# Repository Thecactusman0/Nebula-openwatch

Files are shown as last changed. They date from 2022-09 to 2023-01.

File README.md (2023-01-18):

# Nebula-openwatch
Nebula is a ESP32 based smartwatch proof of concept that features a rotating bezel encoder along with a suite of sensors and parts. This includes:

-ESP32-S3-MINI with wifi and bluetooth LE capabilities

-3 pushbuttons, 2 programmable

-I2C Ambient light sensor for automatic screen dimming

-Onboard lipo charging

-Onboard ldo regulator with voltage supervisor

-I2S amplifier for audio output (BLUETOOTH LE DOES NOT SUPPORT STREAMING AUDIO,CHANGES ARE NEEDED TO BOARD TO ENABLE USE OF THIS CHIP)

-I2S Mems microphone for  audio input(BLUETOOTH LE DOES NOT SUPPORT STREAMING AUDIO)

-I2C RTC module (HASNT BEEN SUFFICENTLY TESTED)

-Haptic vibration motor for user feedback

-4 pin dock connector (2.54 female header) for use with dock that provides serial programming and power.

-I2C 3 axis gyroscope and accelerometer

-200mah lipo battery

Total size is ~44mm diameter, ~12mm height

DO NOT BUILD PROOF OF CONCEPT FOR REFERENCE ONLY

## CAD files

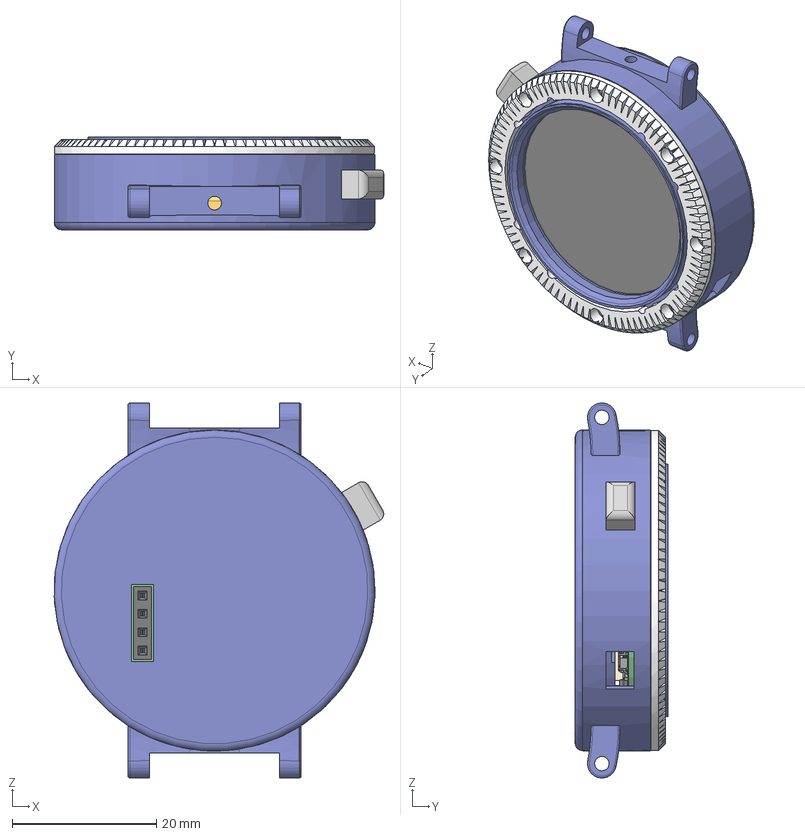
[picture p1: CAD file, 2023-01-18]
Nebula - Master/3D print models/Nebula V2 Bearing type v4.step
45.7 x 12.8 x 52.0 mm
Nebula PCB
Glass
Display
Brass fitting x 4
Resistor - 0603 x 3
Capacitor - 0603 x 5
JST - PH - SMD (R) - 8Pin - 2.00mm
SOT23-3
SOT23-5
Esp module
Battery 200
Case
Bottom
Ring
Button

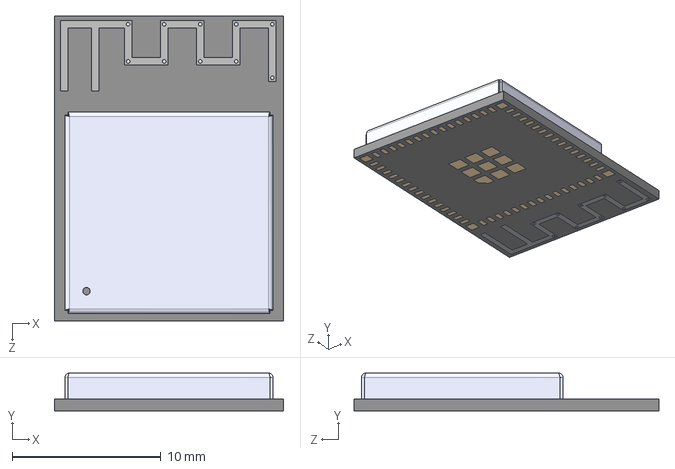
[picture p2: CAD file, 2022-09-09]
Nebula - Master/Footprint/ESP32-S3-MINI-1-N8.step
15.4 x 2.55 x 20.5 mm

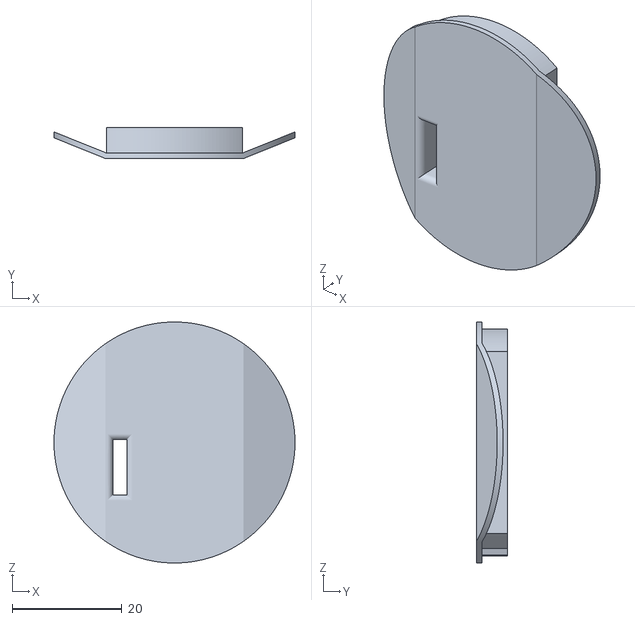
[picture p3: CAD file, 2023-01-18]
Nebula - Master/Kicad/Watch/bottom2.stl
44.0 x 5.65 x 44.0

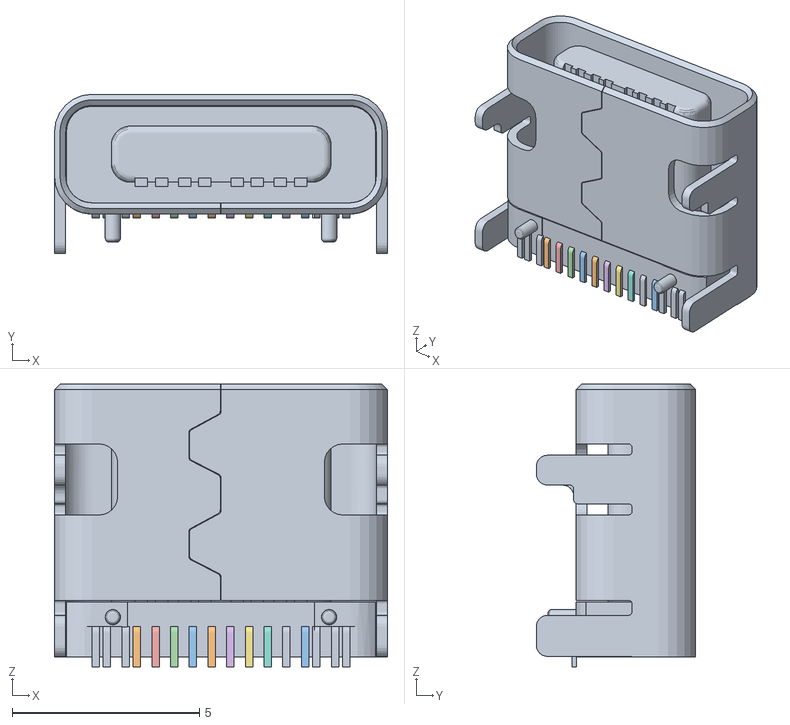
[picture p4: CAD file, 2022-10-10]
Nebula - Master/Models/u262-16xn-4bvc11.obj
8.90 x 4.26 x 7.56
u262-16xn-4bvc11_1
u262-16xn-4bvc11_2
u262-16xn-4bvc11_3
u262-16xn-4bvc11_4
u262-16xn-4bvc11_5
u262-16xn-4bvc11_6
u262-16xn-4bvc11_7
u262-16xn-4bvc11_8
u262-16xn-4bvc11_9
u262-16xn-4bvc11_10
u262-16xn-4bvc11_11

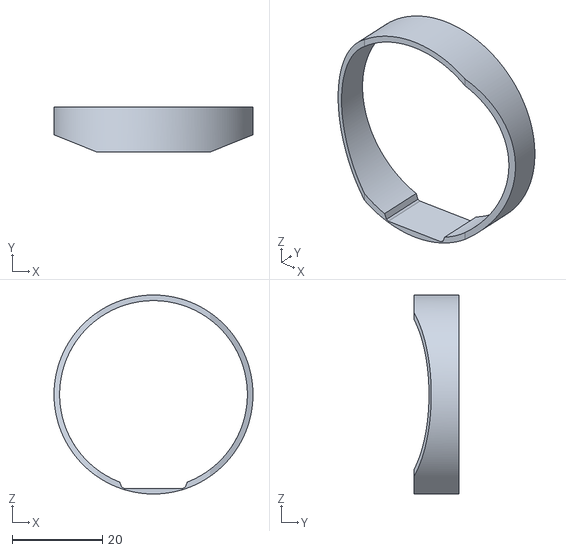
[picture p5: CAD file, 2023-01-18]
Nebula - Master/Kicad/Watch/case2.stl
44.0 x 10.0 x 44.0

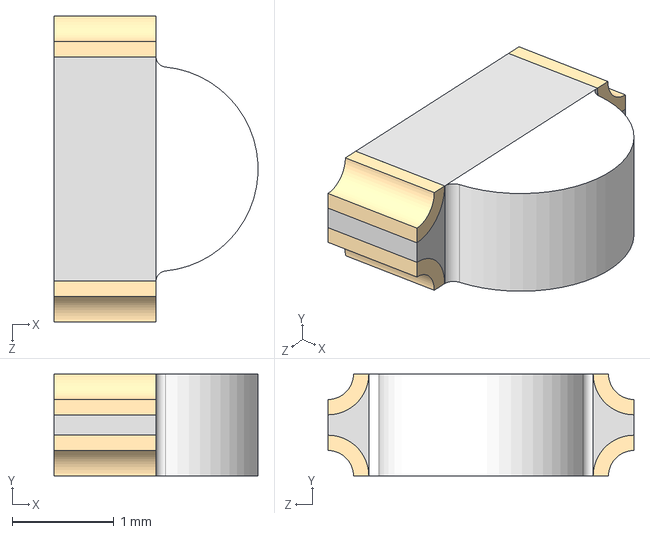
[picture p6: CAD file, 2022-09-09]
Nebula - Master/Models/LTST-S326KGJRKT.step
2.00 x 1.00 x 3.00 mm

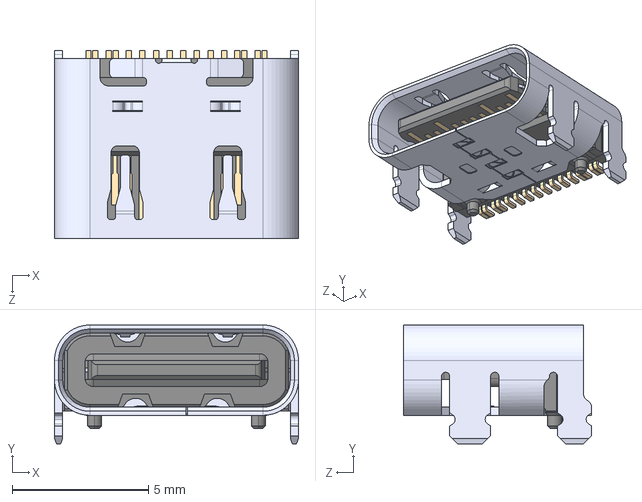
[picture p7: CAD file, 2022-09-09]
Nebula - Master/Models/DX07S016JA1R1500.step
8.94 x 4.36 x 6.90 mm

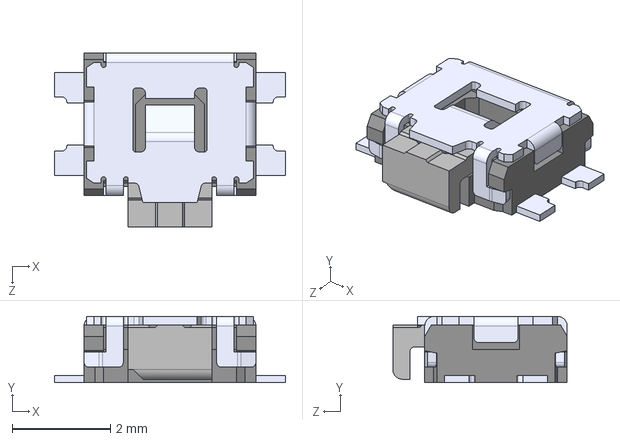
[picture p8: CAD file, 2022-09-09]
Nebula - Master/Models/EVQ-P7J01P.step
4.70 x 1.35 x 3.55 mm

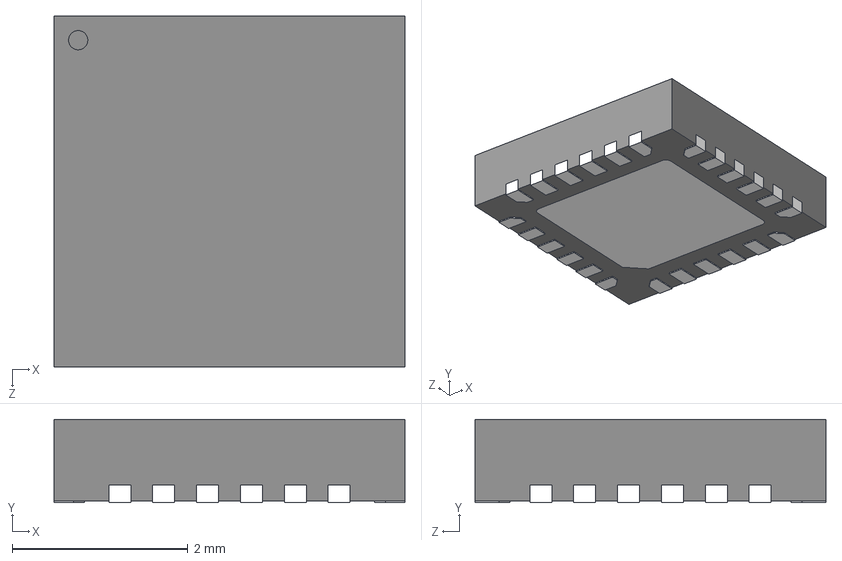
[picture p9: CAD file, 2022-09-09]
Nebula - Master/Models/MPU6050.step
4.00 x 0.95 x 4.00 mm

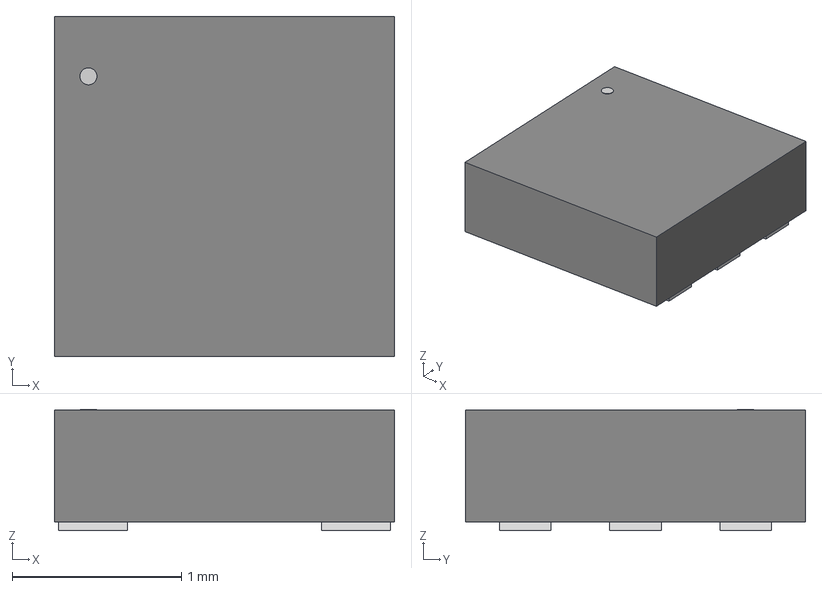
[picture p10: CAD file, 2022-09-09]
Nebula - Master/Models/LTR-303ALS-01_LTO.step
2.01 x 2.01 x 0.714 mm

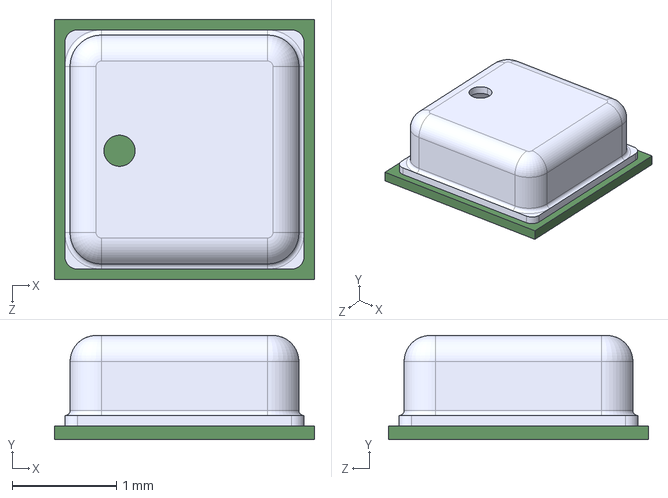
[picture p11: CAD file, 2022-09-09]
Nebula - Master/Models/BME280.step
2.50 x 1.00 x 2.50 mm

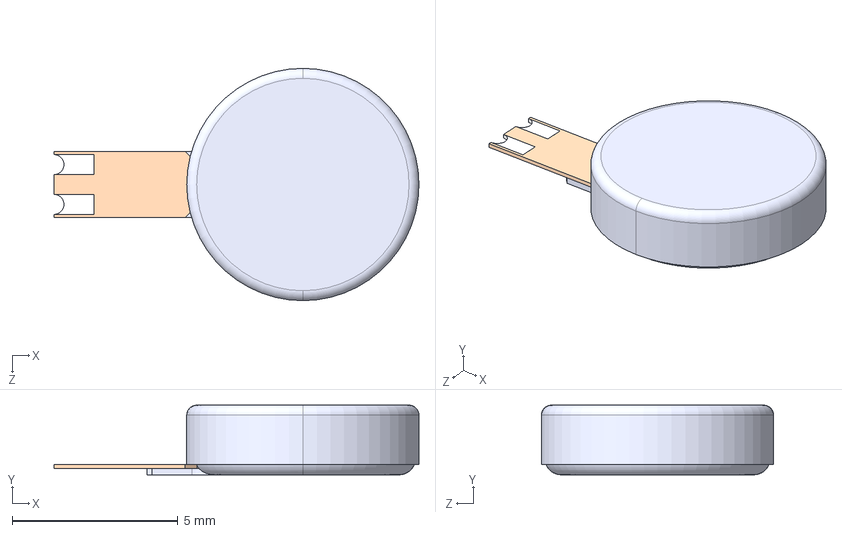
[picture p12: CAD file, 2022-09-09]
Nebula - Master/Models/C0720B001F.step
11.0 x 2.10 x 7.00 mm

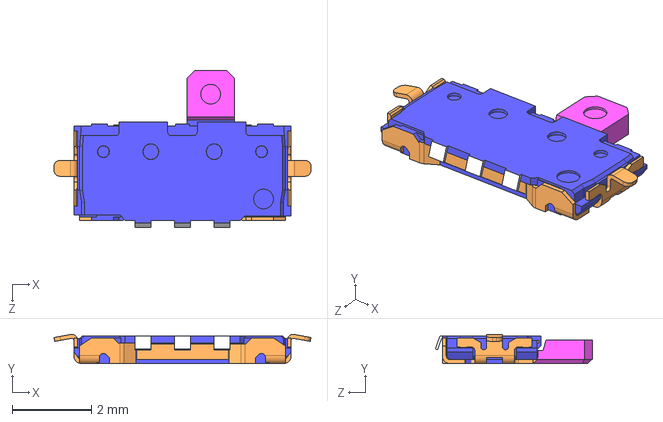
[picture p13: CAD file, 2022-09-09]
Nebula - Master/Models/SSAJ120100.STEP
6.50 x 0.74 x 3.98 mm

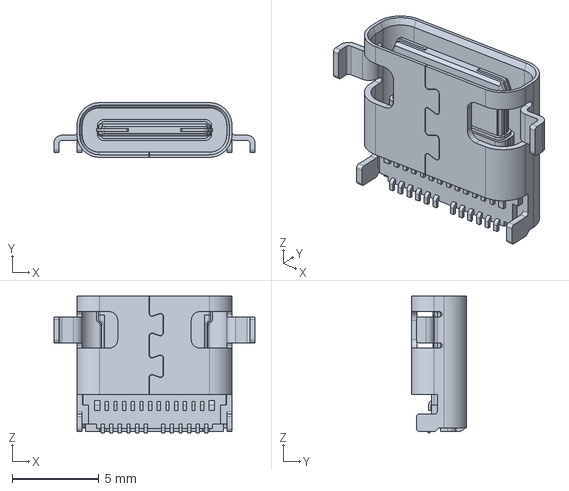
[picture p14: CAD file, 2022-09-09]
Nebula - Master/Models/1054550101.step
11.6 x 3.16 x 7.90 mm

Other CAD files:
Nebula - Master/Models/MCP73831T-2ATI_OT.step

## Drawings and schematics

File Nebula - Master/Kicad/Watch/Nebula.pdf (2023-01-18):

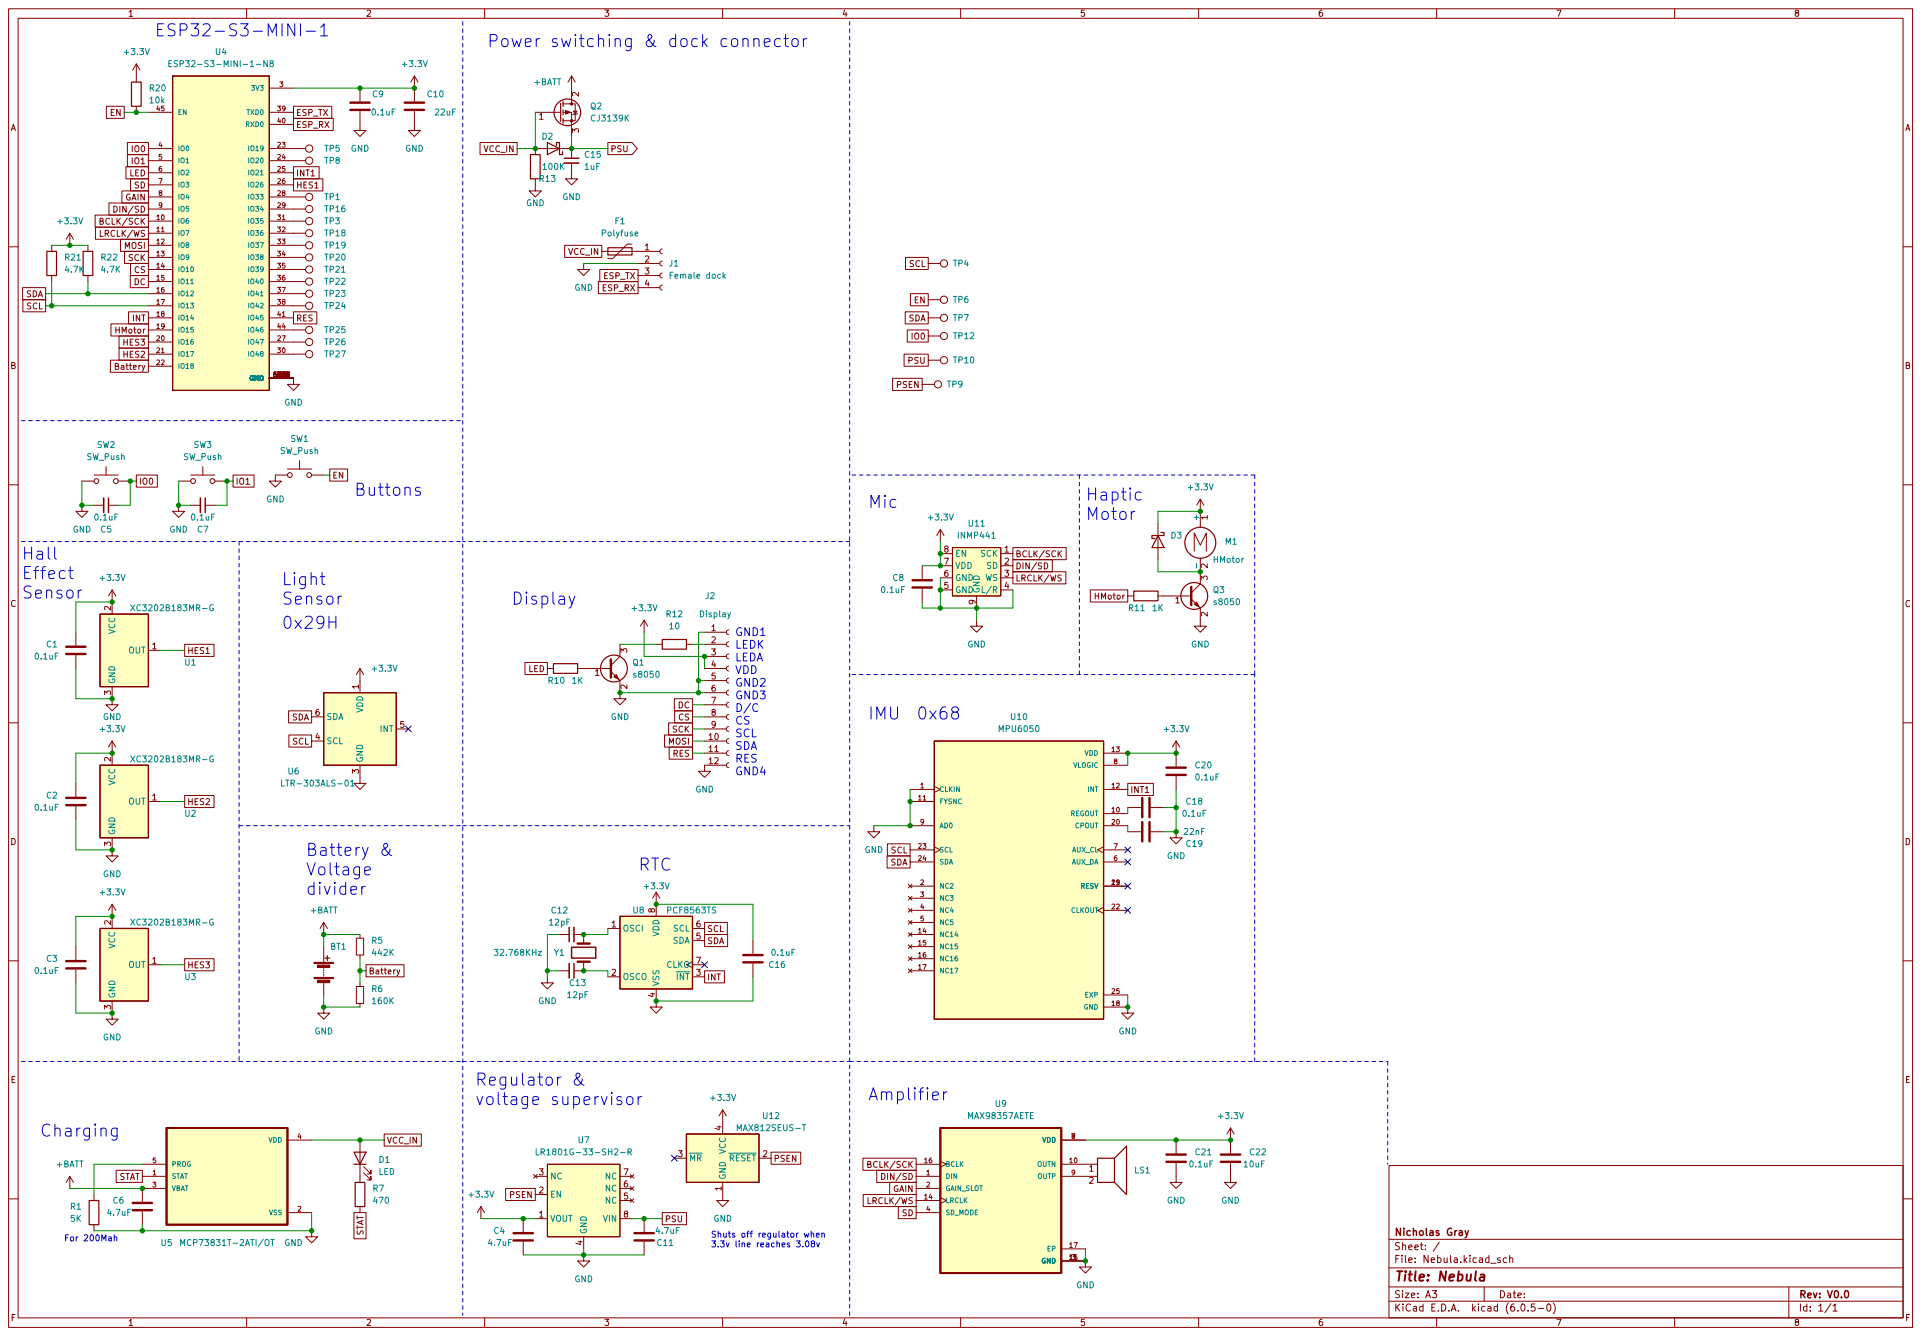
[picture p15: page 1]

Power switching & dock connector

Shuts off regulator when
3.3v line reaches 3.08v

File: Nebula.kicad_sch Sheet: / Nicholas Gray

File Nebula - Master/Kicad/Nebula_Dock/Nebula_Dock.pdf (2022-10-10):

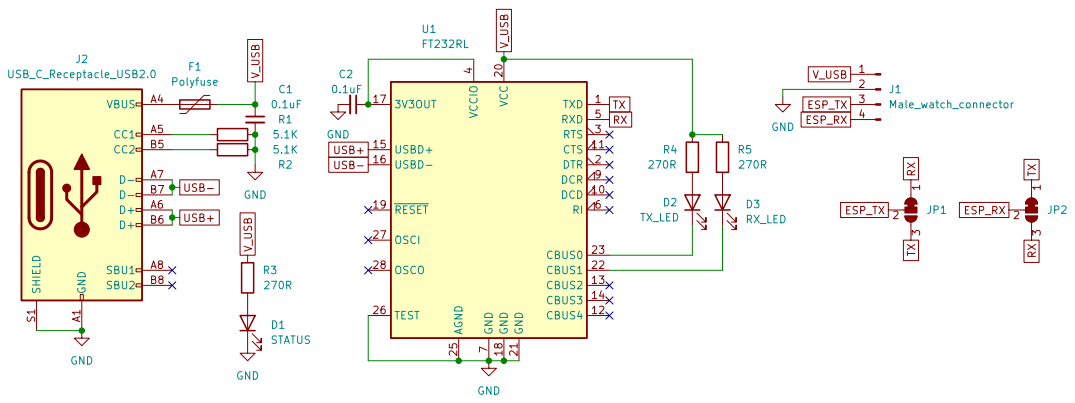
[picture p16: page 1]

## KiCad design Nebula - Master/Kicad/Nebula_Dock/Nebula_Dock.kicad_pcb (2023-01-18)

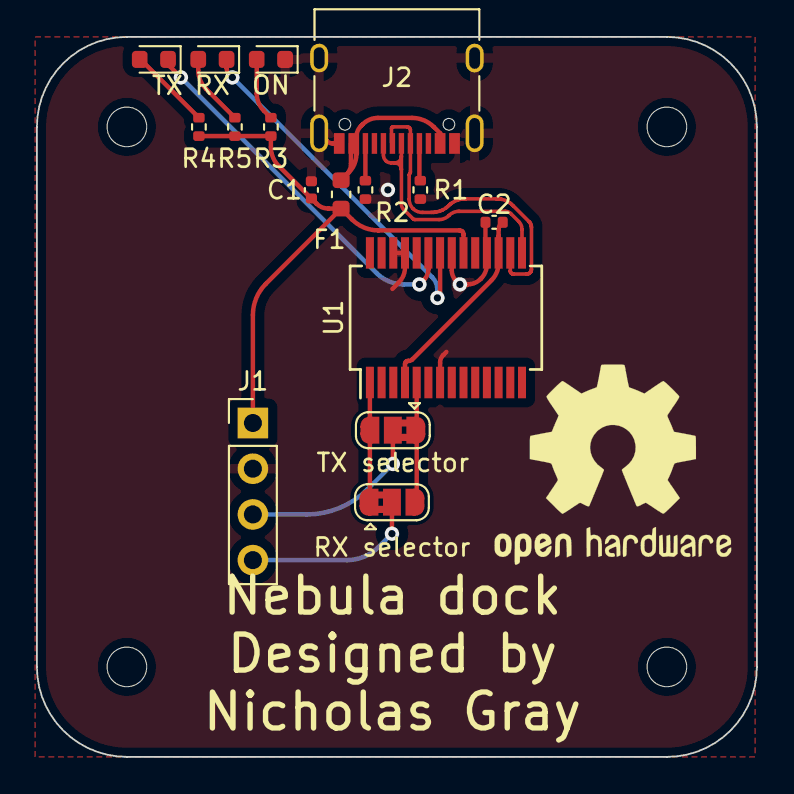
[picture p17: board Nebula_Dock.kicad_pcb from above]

Board: 2 copper layers, 40.0 x 40.0 mm, 20 parts (0 on the bottom side), 17 nets.

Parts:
C1, C2: 0.1uF; C_0402_1005Metric
F1: Polyfuse; Fuse_0603_1608Metric
J1: Male_watch_connector; PinHeader_1x04_P2.54mm_Vertical
J2: USB_C_Receptacle_USB2.0; USB_C_Receptacle_XKB_U262-16XN-4BVC11
ON: STATUS; LED_0603_1608Metric
R1, R2: 5.1K; R_0402_1005Metric
R3, R4, R5: 270R; R_0402_1005Metric
REF1, REF2, REF3, REF4: MountingHole_2.2mm_M2
RX: RX_LED; LED_0603_1608Metric
RX selector: SolderJumper_3_Bridged12; SolderJumper-3_P1.3mm_Bridged2Bar12_RoundedPad1.0x1.5mm
TX: TX_LED; LED_0603_1608Metric
TX selector: SolderJumper_3_Bridged12; SolderJumper-3_P1.3mm_Bridged2Bar12_RoundedPad1.0x1.5mm
U1: FT232RL; SSOP-28_5.3x10.2mm_P0.65mm

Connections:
ESP_RX: J1.4, RX selector.2 (C)
ESP_TX: J1.3, TX selector.2 (C)
GND: C1.2, C2.2, J1.2, J2.A1 (GND), J2.A12 (GND), J2.B1 (GND), J2.B12 (GND), J2.S1 (SHIELD), ON.1 (K), R1.2, R2.1, U1.7 (GND), U1.18 (GND), U1.21 (GND), U1.25 (AGND), U1.26 (TEST)
unnamed: C2.1, U1.4 (VCCIO), U1.17 (3V3OUT)
unnamed: ON.2 (A), R3.2
unnamed: TX.1 (K), U1.23 (CBUS0)
unnamed: R4.2, TX.2 (A)
unnamed: RX.1 (K), U1.22 (CBUS1)
unnamed: R5.2, RX.2 (A)
unnamed: F1.1, J2.A4 (VBUS), J2.A9 (VBUS), J2.B4 (VBUS), J2.B9 (VBUS)
unnamed: J2.A5 (CC1), R1.1
unnamed: J2.B5 (CC2), R2.2
RX: RX selector.3 (B), TX selector.1 (A), U1.5 (RXD)
TX: RX selector.1 (A), TX selector.3 (B), U1.1 (TXD)
USB+: J2.A6 (D+), J2.B6 (D+), U1.15 (USBD+)
USB-: J2.A7 (D-), J2.B7 (D-), U1.16 (USBD-)
V_USB: C1.1, F1.2, J1.1, R3.1, R4.1, R5.1, U1.20 (VCC)

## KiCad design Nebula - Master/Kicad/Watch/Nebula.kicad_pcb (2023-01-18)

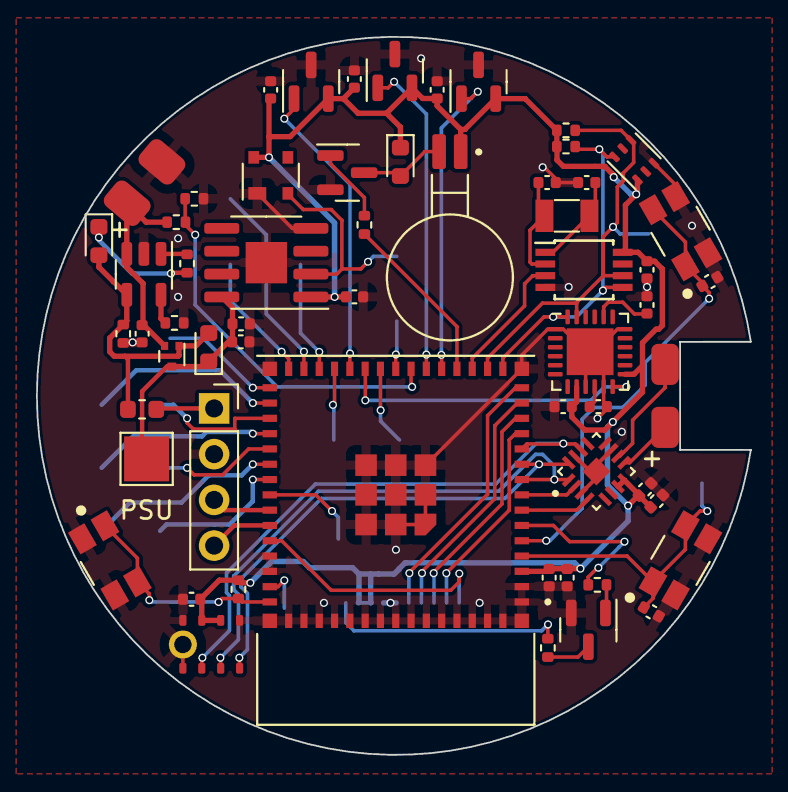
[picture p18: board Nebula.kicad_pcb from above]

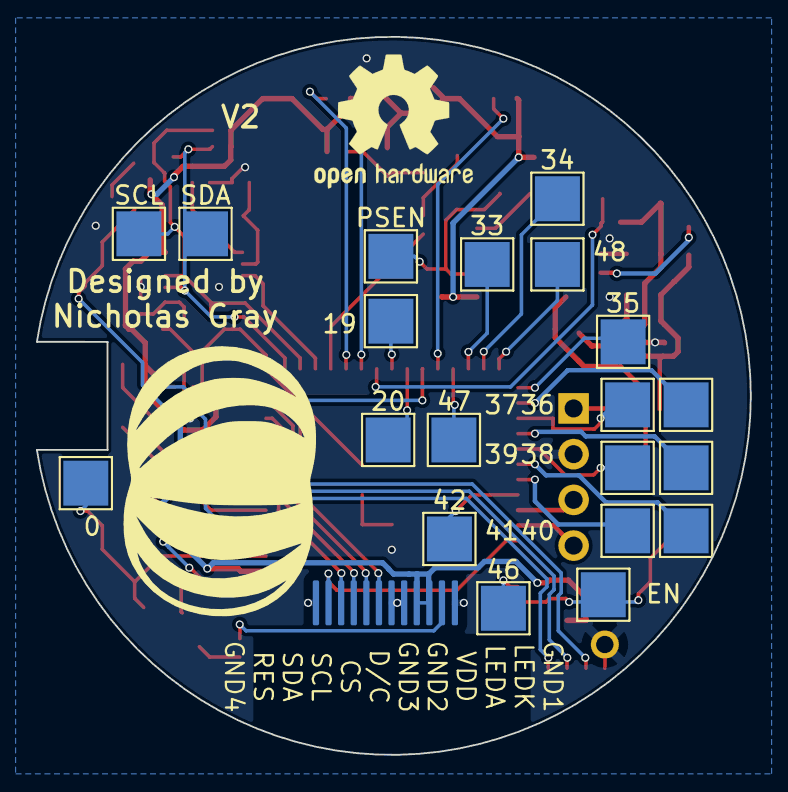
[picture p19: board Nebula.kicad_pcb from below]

Board: 2 copper layers, 39.7 x 39.9 mm, 80 parts (22 on the bottom side), 61 nets.

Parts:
0, 19, 20, 33, 34, 35, 36, 37, 38, 39, 40, 41, 42, 46, 47, 48: TestPoint; TestPoint_Pad_2.5x2.5mm
BT1: Battery; Batt
C1, C2, C3, C5, C7, C8, C9, C16, C18, C20, C21: 0.1uF; C_0402_1005Metric
C4, C6, C11: 4.7uF; C_0402_1005Metric
C10: 22uF; C_0402_1005Metric
C12, C13: 12pF; C_0402_1005Metric
C15: 1uF; C_0402_1005Metric
C19: 22nF; C_0402_1005Metric
C22: 10uF; C_0402_1005Metric
D1: LED; LED_0603_1608Metric
D2, D3: SD0805S020S1R0; D_0603_1608Metric
EN: TestPoint; TestPoint_Pad_2.5x2.5mm
F1: Polyfuse; Fuse_0603_1608Metric
J1: Female dock; PinSocket_1x04_P2.54mm_Vertical
J2: Display; Circular Display connector
LS1: Speaker; Speaker6mm
M1: HMotor; XDCR_C0720B001F
PSEN: TestPoint; TestPoint_Pad_2.5x2.5mm
PSU: TestPoint; TestPoint_Pad_2.5x2.5mm
Q1, Q3: s8050; SOT-23
Q2: CJ3139K; SOT-723
R1: 5K; R_0402_1005Metric
R5: 442K; R_0402_1005Metric
R6: 160K; R_0402_1005Metric
R7: 470; R_0402_1005Metric
R10, R11: 1K; R_0402_1005Metric
R12: 10; R_0402_1005Metric
R13: 100K; R_0402_1005Metric
R20: 10k; R_0402_1005Metric
R21, R22: 4.7K; R_0402_1005Metric
SCL: TestPoint; TestPoint_Pad_2.5x2.5mm
SDA: TestPoint; TestPoint_Pad_2.5x2.5mm
SW1, SW2, SW3: SW_Push; SW_EVQ-P7J01P
U1, U2, U3: XC3202B183MR-G; SOT-23
U4: ESP32-S3-MINI-1-N8; XCVR_ESP32-S3-MINI-1-N8
U5: MCP73831T-2ATI/OT; SOT-23-5
U6: LTR-303ALS-01; Lite-On_LTR-303ALS-01
U7: LR1801G-33-SH2-R; HSOP-8-1EP_3.9x4.9mm_P1.27mm_EP2.3x2.3mm
U8: PCF8563TS; TSSOP-8_3x3mm_P0.65mm
U9: MAX98357AETE; QFN50P300X300X80-17N
U10: MPU6050; QFN-24-1EP_4x4mm_P0.5mm_EP2.6x2.6mm
U11: INMP441
U12: MAX811TEUS-T; SOT-143
Y1: 32.768KHz; Crystal_SMD_3215-2Pin_3.2x1.5mm

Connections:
+3V3: C1.1, C2.1, C3.1, C4.1, C8.2, C9.1, C10.1, C16.2, C20.2, C21.1, C22.1, D3.1 (K), J2.3, J2.4, M1.1 (+), R20.1, R21.1, R22.1, U1.2 (VCC), U2.2 (VCC), U3.2 (VCC), U4.3 (3V3), U6.1 (VDD), U7.1 (VOUT), U8.8 (VDD), U9.7 (VDD), U9.8 (VDD), U10.8 (VLOGIC), U10.13 (VDD), U11.7 (VDD), U11.8 (EN), U12.4 (VCC)
+BATT: BT1.1 (+), C6.1, Q2.2 (D), R5.1, U5.3 (VBAT)
BCLK/SCK: U4.10 (IO6), U9.16 (BCLK), U11.1 (SCK)
Battery: R5.2, R6.1, U4.22 (IO18)
CS: J2.8, U4.14 (IO10)
DC: J2.7, U4.15 (IO11)
DIN/SD: U4.9 (IO5), U9.1 (DIN), U11.2 (SD)
EN: EN.1, R20.2, SW1.1, U4.45 (EN)
ESP_RX: J1.4, U4.40 (RXD0)
ESP_TX: J1.3, U4.39 (TXD0)
GAIN: U4.8 (IO4), U9.2 (GAIN_SLOT)
GND: BT1.2 (-), C1.2, C2.2, C3.2, C4.2, C5.2, C6.2, C7.2, C8.1, C9.2, C10.2, C11.1, C12.1, C13.2, C15.2, C16.1, C18.2, C19.1, C20.1, C21.2, C22.2, J1.2, J2.1, J2.5, J2.6, J2.12, Q1.2 (E), Q3.2 (E), R1.1, R6.2, R13.1, SW1.2, SW2.2, SW3.2, U1.3 (GND), U2.3 (GND), U3.3 (GND), U4.1 (GND), U4.2 (GND), U4.42 (GND), U4.43 (GND), U4.46 (GND), U4.47 (GND), U4.48 (GND), U4.49 (GND), U4.50 (GND), U4.51 (GND), U4.52 (GND), U4.53 (GND), U4.54 (GND), U4.55 (GND), U4.56 (GND), U4.57 (GND), U4.58 (GND), U4.59 (GND), U4.60 (GND), U4.61 (GND), U4.61_1 (GND), U4.61_2 (GND), U4.61_3 (GND), U4.61_4 (GND), U4.61_5 (GND), U4.61_6 (GND), U4.61_7 (GND), U4.61_8 (GND), U4.62 (GND), U4.63 (GND), U4.64 (GND), U4.65 (GND), U5.2 (VSS), U6.3 (GND), U7.4 (GND), U8.4 (VSS), U9.3 (GND), U9.11 (GND), U9.15 (GND), U9.17 (EP), U10.1 (CLKIN), U10.9 (AD0), U10.11 (FYSNC), U10.18 (GND), U10.25 (EXP), U11.4 (L/R), U11.5 (GND), U11.6 (GND), U11.9 (GND), U12.1 (GND)
HES1: U1.1 (OUT), U4.26 (IO26)
HES2: U2.1 (OUT), U4.21 (IO17)
HES3: U3.1 (OUT), U4.20 (IO16)
HMotor: R11.1, U4.19 (IO15)
INT: U4.18 (IO14), U8.3 (~INT)
INT1: U4.25 (IO21), U10.12 (INT)
IO0: 0.1, C5.1, SW2.1, U4.4 (IO0)
IO1: C7.1, SW3.1, U4.5 (IO1)
LED: R10.1, U4.6 (IO2)
LRCLK/WS: U4.11 (IO7), U9.14 (LRCLK), U11.3 (WS)
MOSI: J2.10, U4.12 (IO8)
unnamed: C12.2, U8.1 (OSCI), Y1.2
unnamed: C13.1, U8.2 (OSCO), Y1.1
unnamed: C18.1, U10.10 (REGOUT)
unnamed: C19.2, U10.20 (CPOUT)
unnamed: D3.2 (A), M1.2 (-), Q3.3 (C)
unnamed: F1.2, J1.1
unnamed: J2.2, R12.2
unnamed: LS1.1, U9.10 (OUTN)
unnamed: LS1.2, U9.9 (OUTP)
unnamed: Q1.1 (B), R10.2
unnamed: Q1.3 (C), R12.1
unnamed: Q3.1 (B), R11.2
unnamed: R1.2, U5.5 (PROG)
unnamed: D1.1 (K), R7.2
unnamed: 33.1, U4.28 (IO33)
unnamed: 35.1, U4.31 (IO35)
unnamed: 19.1, U4.23 (IO19)
unnamed: 20.1, U4.24 (IO20)
unnamed: 34.1, U4.29 (IO34)
unnamed: 36.1, U4.32 (IO36)
unnamed: 37.1, U4.33 (IO37)
unnamed: 38.1, U4.34 (IO38)
unnamed: 39.1, U4.35 (IO39)
unnamed: 40.1, U4.36 (IO40)
unnamed: 41.1, U4.37 (IO41)
unnamed: 42.1, U4.38 (IO42)
unnamed: 46.1, U4.44 (IO46)
unnamed: 47.1, U4.27 (IO47)
unnamed: 48.1, U4.30 (IO48)
PSEN: PSEN.1, U7.2 (EN), U12.2 (~RESET)
PSU: C11.2, C15.1, D2.1 (K), PSU.1, Q2.3 (S), U7.8 (VIN)
RES: J2.11, U4.41 (IO45)
SCK: J2.9, U4.13 (IO9)
SCL: R21.2, SCL.1, U4.17 (IO13), U6.4 (SCL), U8.6 (SCL), U10.23 (SCL)
SD: U4.7 (IO3), U9.4 (SD_MODE)
SDA: R22.2, SDA.1, U4.16 (IO12), U6.6 (SDA), U8.5 (SDA), U10.24 (SDA)
STAT: R7.1, U5.1 (STAT)
VCC_IN: D1.2 (A), D2.2 (A), F1.1, Q2.1 (G), R13.2, U5.4 (VDD)

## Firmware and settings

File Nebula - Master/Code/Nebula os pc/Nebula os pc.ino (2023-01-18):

#include "buttonsMenu.h"
#include "functions.h"
//#include "wifi_update.h"
TFT_eSPI tft = TFT_eSPI();
Adafruit_MPU6050 mpu;
sensors_event_t a, g, temp;
RTC_PCF8523 rtc;
void setup() {
/*
WiFi.mode(WIFI_STA);
  WiFi.begin(ssid, password);
  while (WiFi.waitForConnectResult() != WL_CONNECTED) {
    Serial.println("Connection Failed! Rebooting...");
    delay(5000);
    ESP.restart();
  }
 arduinoOTA();
*/
    Wire.begin(12,13);
    mpu.begin();
    rtc.begin();
    rtc.adjust(DateTime(F(__DATE__), F(__TIME__)));
    rtc.start();
    tft.init();
    tft.begin();
    tft.setRotation(0);        // rotate screen to be right
    tft.fillScreen(TFT_BLACK);//clear screen
    //mpu.setAccelerometerRange(MPU6050_RANGE_8_G);
   mpu.setGyroRange(MPU6050_RANGE_2000_DEG);
    //mpu.setFilterBandwidth(MPU6050_BAND_21_HZ);
    pinMode(0,INPUT_PULLUP);
    pinMode(1,INPUT_PULLUP);//setup button pins as inputs
Serial.begin(115200);
Serial.print("we are up");
tft.fillRectVGradient(0, 0, 240,240,TFT_BLACK,0x7215);
}

void loop() {
homePressed = digitalRead(0);
selectPressed = digitalRead(1);
homeCheck();
selectCheck();
drawMenu();
// ArduinoOTA.handle();
}

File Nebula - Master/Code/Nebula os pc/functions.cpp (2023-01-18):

#include "functions.h"
#include "buttonsMenu.h"

int lastState12;
int lastState22;
int lastState32;
int state12;
int state22;
int state32;
bool selectorRedrawProtect = false;
int menu =0;
int item =0;
bool redrawProtect = false;
bool homeIncrementProtect = true; //stops from immediately going through all menus
bool selectIncrementProtect = true; //stops from immediately going through all menus
bool homePressed = true;
bool selectPressed = true;

unsigned long time_now = 0;
bool running = false;
bool replayProtect = false;

  unsigned long previousMillis = 0;

  const long interval = 15000;

unsigned long theMillis;

String theTime;
bool BL = true;
  unsigned int durMM2;
   unsigned int durHH2;
   


int currentHour;
int currentMinute;
int RTCSetting;








String timeMillis2(unsigned long Hourtime,unsigned long Mintime)
{
  String dataTemp = "";

  if (Hourtime < 10)
  {
    dataTemp = dataTemp + "0" + String(Hourtime)+':';
  }
  else if (Hourtime >9&&Hourtime < 13)
  {
    dataTemp = dataTemp + String(Hourtime)+':';
  }
  else{
    dataTemp = dataTemp + String(Hourtime-12)+':';
  }
  
  if (Mintime < 10)
  {
    dataTemp = dataTemp + "0" + String(Mintime);
  }
  else{
    dataTemp = dataTemp + String(Mintime);
  }
 
  return dataTemp;
}

void timeWithMillis(){
DateTime now = rtc.now();
int beans;
if (beans = 0){
 currentHour = now.hour();
 currentMinute = now.minute();
 beans = 1;
}
unsigned long int  timeMillis = (now.hour()*3600000)+(now.minute()*60000)+millis();
//Serial.println(timeMillis);
  
  
    durMM2 = ( timeMillis/60000)%60; //Minutes
   durHH2 = ( timeMillis/3600000);  //Hours
   durHH2 = durHH2 % 24;
//Serial.println(durMM2);
//Serial.println(durHH2);
   theTime = timeMillis2(durHH2,durMM2);
   //Serial.print(theTime);
}


void drawRTCAdjust(){
  pinMode(16, INPUT_PULLUP);
pinMode(17, INPUT_PULLUP);
pinMode(19, INPUT_PULLUP);
  state12 = digitalRead(19)  ;
state22 = digitalRead(17)  ;
state32 = digitalRead(16)  ;
if(RTCSetting == 1){
  tft.setTextColor(TFT_BLACK,TFT_WHITE);
  tft.setCursor(centrex-50,centrey);
  tft.println(currentHour);
  tft.setTextColor(TFT_WHITE,TFT_BLACK);
  tft.setCursor(centrex-20,centrey);
  tft.println(":");
  tft.setCursor(centrex+10,centrey);
  tft.println(currentMinute);
}else if (RTCSetting == 2){
    tft.setTextColor(TFT_WHITE,TFT_BLACK);
  tft.setCursor(centrex-50,centrey);
  tft.println(currentHour);

  tft.setCursor(centrex-20,centrey);
  tft.println(":");
    tft.setTextColor(TFT_BLACK,TFT_WHITE);
  tft.setCursor(centrex+10,centrey);
  tft.println(currentMinute);
}else{
      tft.setTextColor(TFT_WHITE,TFT_BLACK);
  tft.setCursor(centrex-50,centrey);
tft.println(currentHour);
tft.setCursor(centrex-20,centrey);
  tft.println(":");
  tft.setCursor(centrex+10,centrey);
  tft.println(currentMinute);
  
}
 if (RTCSetting == 1){
  if (state12 == 0){
  if (lastState22 == 0){
  currentHour--;
  lastState22 = 1;
  lastState12 = 0;
  redrawProtect = false;
  selectorRedrawProtect = false;
tft.fillScreen(TFT_BLACK);
  }
  if (lastState32 == 0){
  currentHour++;
  lastState32 = 1;
  lastState12 = 0;
redrawProtect = false;
selectorRedrawProtect = false;
tft.fillScreen(TFT_BLACK);
  }
}
if (state22 == 0){
  if (lastState12 == 0){
  currentHour++;
  lastState12 = 1;
  lastState22 = 0;
 redrawProtect = false;
 selectorRedrawProtect = false;
 tft.fillScreen(TFT_BLACK);
  }
  if (lastState32 == 0){
  item--;
  lastState32 = 1;
  lastState22 = 0;
redrawProtect = false;
selectorRedrawProtect = false;
tft.fillScreen(TFT_BLACK);
  }
}
if (state32 == 0){
  if (lastState1 == 0){
  currentHour--;
  lastState12 = 1;
  lastState32 = 0;
 redrawProtect = false;
 selectorRedrawProtect = false;
 tft.fillScreen(TFT_BLACK);
  }
  if (lastState22 == 0){
  currentHour++;
  lastState22 = 1;
  lastState32 = 0;
redrawProtect = false;
selectorRedrawProtect = false;
tft.fillScreen(TFT_BLACK);
  }
}
if(currentHour == 25){
  currentHour=0;
}else if (currentHour == -1){
  currentHour=24;
}
Serial.print(currentHour);

}
}







void sleepManager(){

}


void timeRefresh(){
mpu.getEvent(&a, &g, &temp);

theMillis = millis();
if (g.gyro.x < -13 && a.acceleration.y > 8.5){
BL = true;
Serial.print("with the flick of my wrist");
 previousMillis = theMillis-58000;
}
//Serial.println(g.gyro.x);
  if (theMillis - previousMillis >= interval) {
    previousMillis = theMillis;
    redrawProtect = false;
    BL = false;
     esp_sleep_enable_ext0_wakeup(GPIO_NUM_1,0); //1 = High, 0 = Low
  }
  if(BL == false){
    digitalWrite(2,LOW);
    esp_light_sleep_start();
    menu = 0;
    Serial.print("this where we left off");
    BL = true;
    
    }else{
    digitalWrite(2,HIGH);
    }
}
void RTCtest(){
DateTime now = rtc.now();

    Serial.print(now.year(), DEC);
    Serial.print('/');
    Serial.print(now.month(), DEC);
    Serial.print('/');
    Serial.print(now.day(), DEC);
    Serial.print(" (");
    //print(daysOfTheWeek[now.dayOfTheWeek()]);
    Serial.print(") ");
    Serial.print(now.hour(), DEC);
    Serial.print(':');
    Serial.print(now.minute(), DEC);
    Serial.print(':');
    Serial.print(now.second(), DEC);
    Serial.println();
    delay(3000);
}

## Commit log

2022-09-09 Naming Fix
    [Nebula.kicad_pcb, Nebula.kicad_sch]
2022-09-09 gerber update
    [Nebula-B_Cu.gbr, Nebula-B_Mask.gbr, Nebula-B_Silkscreen.gbr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]
2022-09-13 Removed old gerbers
    [Nebula-B_Cu.gbr, Nebula-B_Mask.gbr, Nebula-B_Silkscreen.gbr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]
2022-09-17 Added BOM and minor changes
    Fixed mosfet footprint and magnetic sensor footprints
    [Nebula.csv, Nebula.kicad_pcb, Nebula.kicad_sch]
2022-10-09 Secondary version
    Upgraded power system with ldo and voltage supervisor.
    Changed some footprints to make more accessible.
    Increased test point size.
    Removed onboard usb c connector and moved to dock assembly, onboard usb c will hopefully return in the next version.
    Fixed problems with io0 holding low.
    Increased power trace thickness.
    Spread out power circuitry for easier assembly and testing.
    Added a new dock pcb with ft232 serial programmer with usb c receptacle.
    Moved speaker footprint to other side for ease of assembly.
    Moved microphone to face directly towards the user.
    Added a festive pumpkin silkscreen image to the dock.
    [Nebula.csv, Nebula.kicad_pcb, Nebula.kicad_sch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]
2022-10-10 Added pcb images, schematic pdf and step
    [Nebula.kicad_pcb, Nebula_Dock.kicad_pcb, u262-16xn-4bvc11.obj]
2022-10-15 changed prgm pin on dock
    [Nebula_Dock.kicad_pcb]
2023-01-18 3d files
    [Nebula V2 Bearing type v4.step, Nebula.kicad_pcb, Nebula_Dock.kicad_pcb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]
